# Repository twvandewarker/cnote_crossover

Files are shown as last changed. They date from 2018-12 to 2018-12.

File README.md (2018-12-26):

# cnote_crossover

This is a crossover board for Parts Express's C-Note bookshelf speaker kit: https://www.parts-express.com/c-note-mt-bookshelf-speaker-kit-pair-with-knock-down-cabinets--300-7140

If you want to check out the EAGLE files, you will probably need my parts library, located here: https://github.com/twvandewarker/eagle_library

The zip folder contains the Gerbers that I sent to get my boards. I used JLCPCB.

This board uses the stock crossover components that come with the kit, plus a 6 pin Phoenix-type connector. The one I used is Wurth Electronics 691241610006 and will fit up to 14AWG wire, but any type of connector with 0.4" pitch will work. The mounting holes are 3.5" square, and you can use up to #8 screws. There are holes milled for 1/8" zip ties for the inductors.

There is a place for the optional .22uF cap in parallel with the woofer's inductor. I used Dayton DMPC-0.22. This was suggested by the speaker's designer in the forums to attenuate the woofer around it's cone breakup.

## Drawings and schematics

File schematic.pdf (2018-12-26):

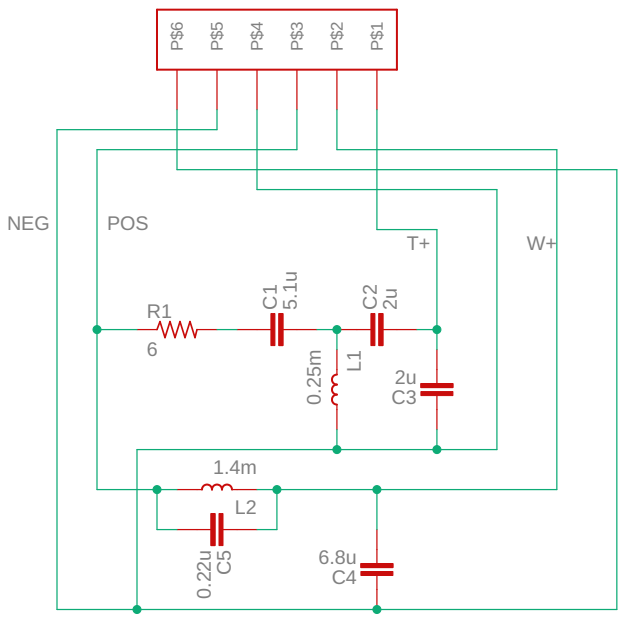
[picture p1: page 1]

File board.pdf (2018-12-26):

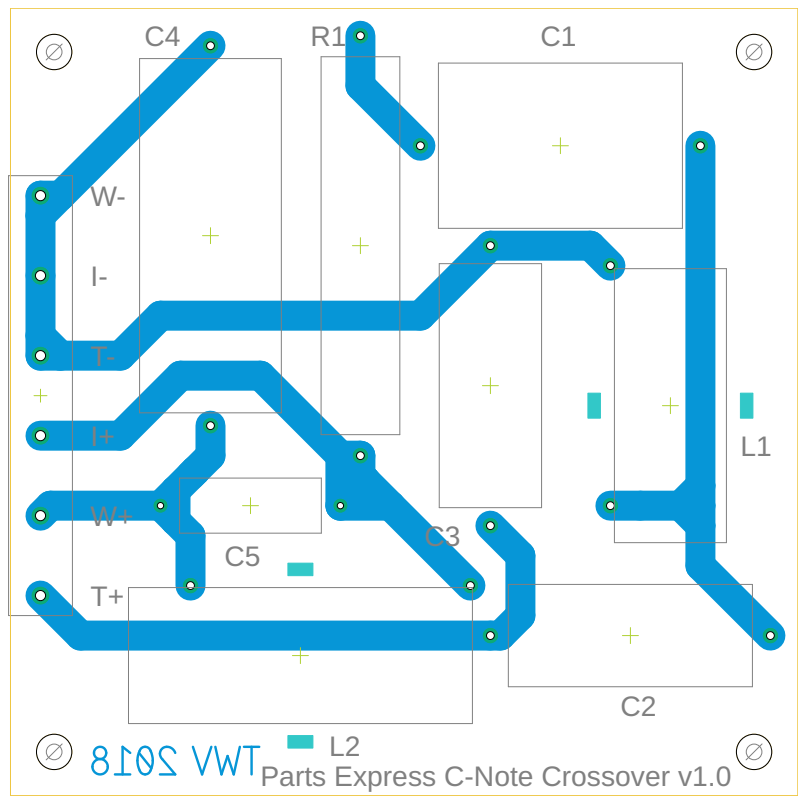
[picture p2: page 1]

Parts Express C-Note Crossover v1.0

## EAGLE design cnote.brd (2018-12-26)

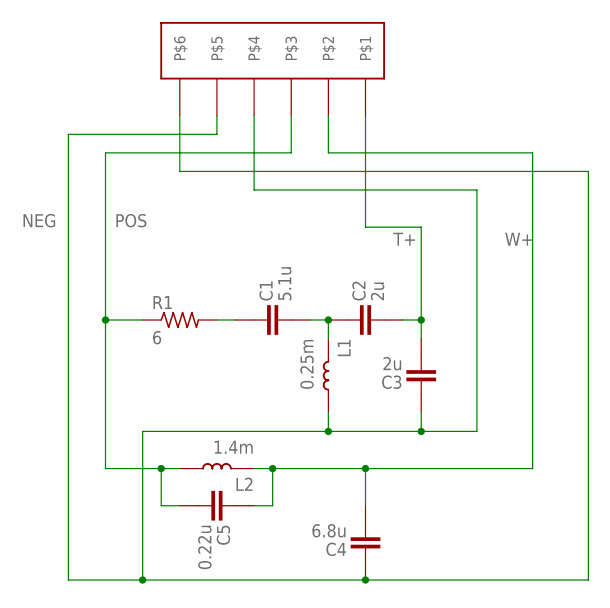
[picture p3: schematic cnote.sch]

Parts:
C1: 5.1u; DAYTON_21X31
C2, C3: 2u; DAYTON_13X31
C4: 6.8u; DAYTON_18X45
C5: 0.22u; DAYTON_7X18
L1: 0.25m; DAYTON_AC20-25
L2: 1.4m; DAYTON_AC201-4
R1: 6; DAYTON_48X10
U$1: WURTH_WR-TBL-2416-6

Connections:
unnamed: C1.P$2 (2), C2.P$1 (1), L1.P$2 (2)
unnamed: C1.P$1 (1), R1.P$2 (2)
NEG: C3.P$1 (1), C4.P$1 (1), L1.P$1 (1), U$1.P$4, U$1.P$5, U$1.P$6
POS: C5.P$2 (2), L2.P$1 (1), R1.P$1 (1), U$1.P$3
T+: C2.P$2 (2), C3.P$2 (2), U$1.P$1
W+: C4.P$2 (2), C5.P$1 (1), L2.P$2 (2), U$1.P$2

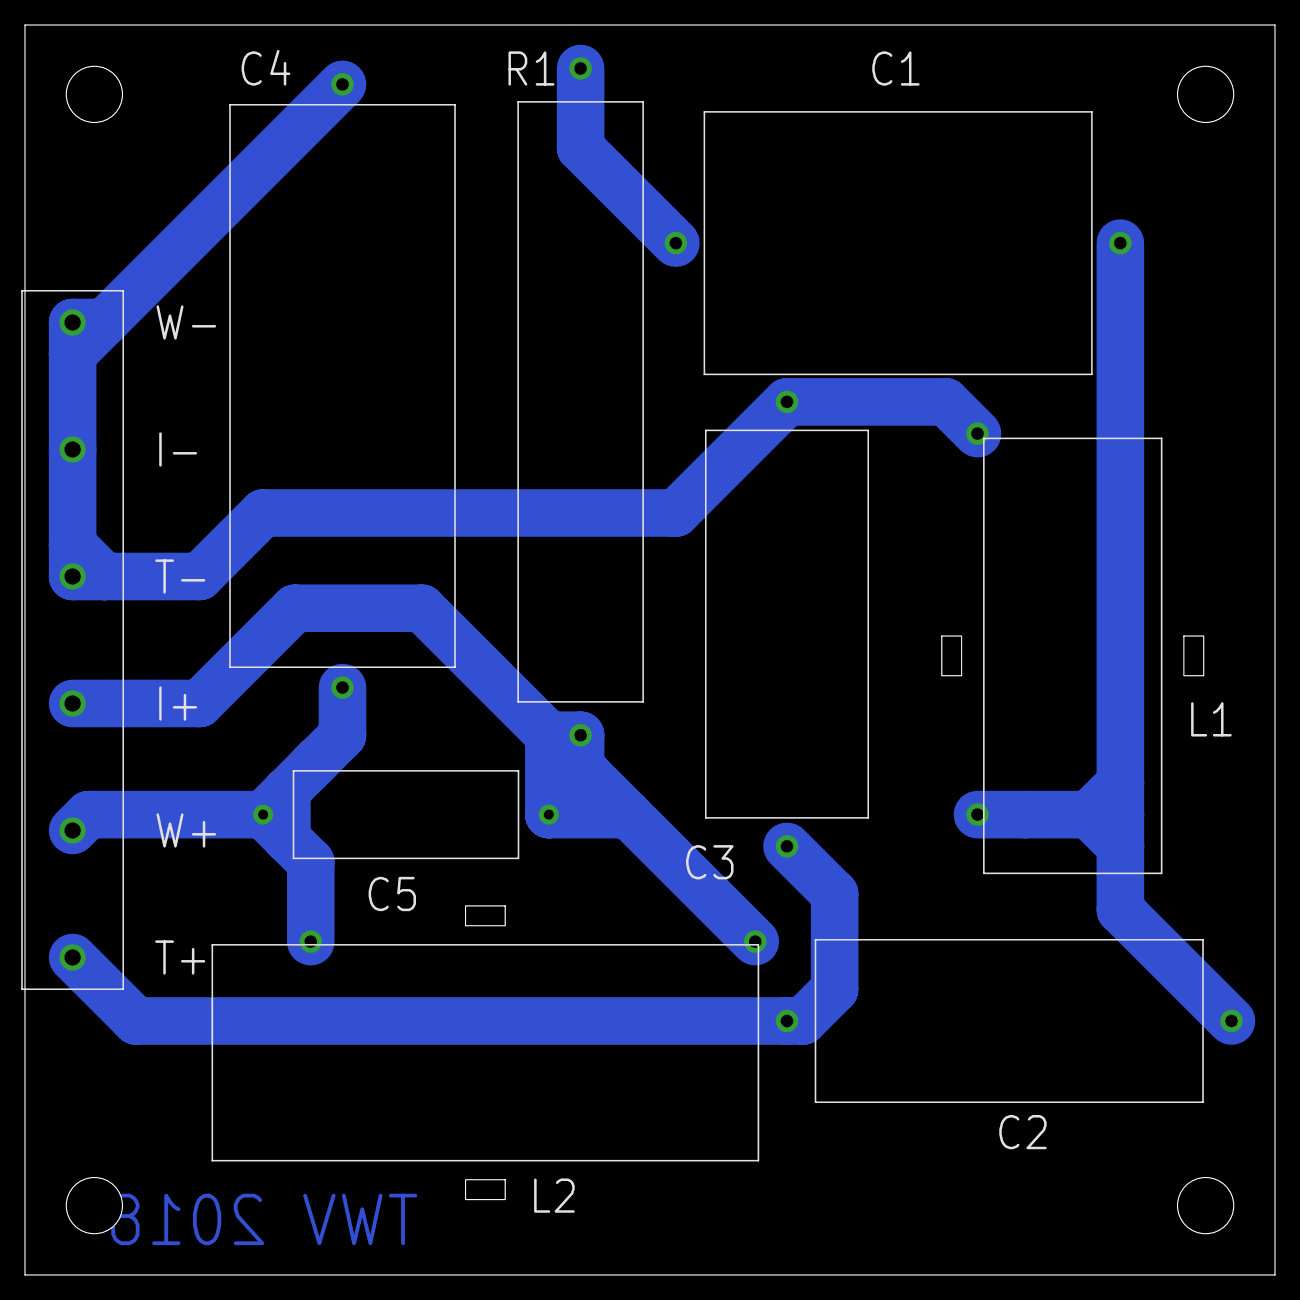
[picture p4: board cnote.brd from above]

Board: 2 copper layers, 100.0 x 100.0 mm, 9 parts (0 on the bottom side), 6 nets.
